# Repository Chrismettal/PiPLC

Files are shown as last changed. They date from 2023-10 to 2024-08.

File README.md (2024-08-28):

# PiPLC <!-- omit in toc -->





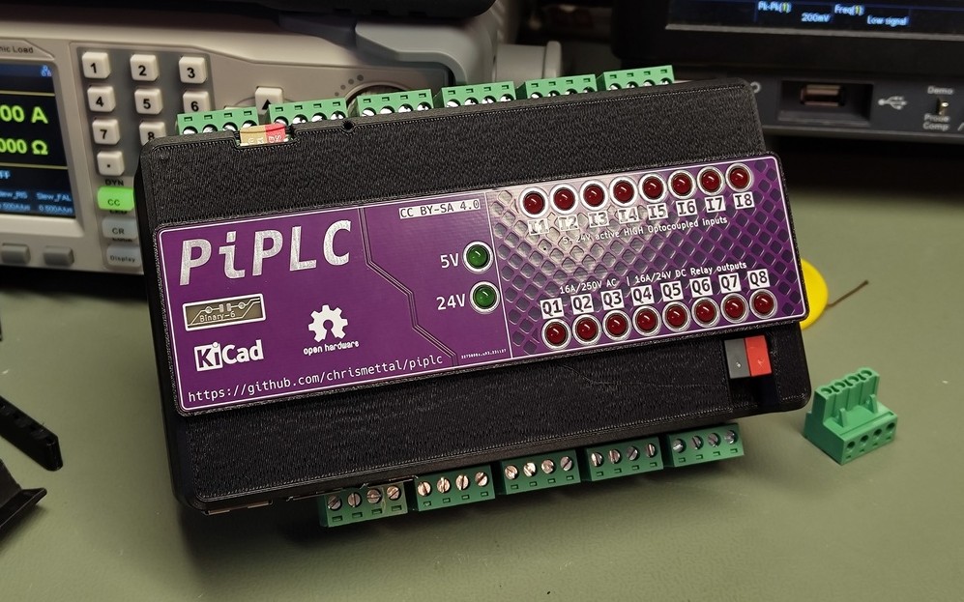
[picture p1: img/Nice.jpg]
Nice


This is a Raspberry Pi breakout board + DIN rail case to use Pis in PLC-like industrial situations.

The design relies on a Raspberry Pi 4 for all functions to work. Pi 5 does also work but won't fit the 3D printed case, while Pi 3 and below don't allow for all functions to be used.

The PiPLC is intended to be used with [Home Assistant](https://www.home-assistant.io/), as well as [OpenPLC](https://autonomylogic.com/).
Obviously, since it's just a breakout board for any Pi, you can run whatever software you want, but Home Assistant and OpenPLC are the ones inspiring the design of this project.

For an example use with your own software, check out [Grass](https://github.com/chrismettal/grass)!

**IO featured on board the PLC are:**

- 8 x 24 V tolerant optocoupled inputs
- 8 x 16A Relays (250 V AC / 24 V DC)
- KNX TP
- Modbus RTU / RS-485
- I²C
- 2 x analog 3.3 V PWM outputs

All the parts are or will be stocked at Tindie!



**If you like my work please consider [supporting me](https://github.com/Chrismettal#donations)!**

## Table of contents <!-- omit in toc -->

- [GPIO mapping](#gpio-mapping)
- [Pinout](#pinout)
- [I/O](#io)
  - [J1 | Power Input](#j1--power-input)
  - [J2 | Modbus](#j2--modbus)
  - [J3 - J6 | Digital Outputs (Q1-8)](#j3---j6--digital-outputs-q1-8)
  - [J7 | PWM](#j7--pwm)
  - [J8 | I²C](#j8--ic)
  - [J9 | 1-Wire](#j9--1-wire)
  - [J10 - J12 | Digital Inputs (I1-8)](#j10---j12--digital-inputs-i1-8)
  - [Wago header | KNX / NCN5121](#wago-header--knx--ncn5121)
- [On board devices](#on-board-devices)
  - [PCF8523 RTC](#pcf8523-rtc)
- [Example Hardware](#example-hardware)
- [Software](#software)
  - [OpenPLC](#openplc)
    - [Installation](#installation)
    - [Example](#example)
  - [Home Assistant](#home-assistant)
    - [Installation](#installation-1)
    - [Example](#example-1)
  - [Codesys](#codesys)
    - [Installation](#installation-2)
    - [Example](#example-2)
- [Raspberry pi configuration](#raspberry-pi-configuration)
  - [`/boot/config.txt`](#bootconfigtxt)
  - [`/boot/cmdline.txt`](#bootcmdlinetxt)
- [Making your own](#making-your-own)
  - [Boards](#boards)
    - [Mainboard](#mainboard)
    - [HMI](#hmi)
    - [Frontpanel](#frontpanel)
    - [Pi Riser](#pi-riser)
    - [HMI Riser](#hmi-riser)
  - [3D printing](#3d-printing)
  - [Impressions](#impressions)
  - [Testing](#testing)
- [Tools used](#tools-used)
- [Sources](#sources)
- [Donations](#donations)
- [License](#license)

---

## GPIO mapping

| GPIO Name | PiPLC function | OpenPLC | Home Assistant | Codesys |
| :---: | :--- | :--- | :--- | :--- |
| `GPIO_02` | :blue_square: I²C SDA | :warning: No driver yet | :warning: To be tested | :warning: To be tested |
| `GPIO_03` | :blue_square: I²C SCL | :warning: No driver yet | :warning: To be tested | :warning: To be tested |
| `GPIO_04` | :blue_square: Modbus TX  | `/dev/ttyAMA3` | `/dev/ttyAMA3` | :warning: To be tested |
| `GPIO_05` | :blue_square: Modbus RX  | `/dev/ttyAMA3` | `/dev/ttyAMA3` | :warning: To be tested |
| `GPIO_06` | :blue_square: Modbus RTS | `/dev/ttyAMA3` | `/dev/ttyAMA3` | :warning: To be tested |
| `GPIO_07` | :red_square: Q4 | `%QX0.3` | :white_check_mark: | :warning: To be tested |
| `GPIO_08` | :red_square: Q3 | `%QX0.2` | :white_check_mark: | :warning: To be tested |
| `GPIO_09` | :yellow_square: I5 | `%IX0.4` | :white_check_mark: | :warning: To be tested |
| `GPIO_10` | :yellow_square: I4 | `%IX0.3` | :white_check_mark: | :warning: To be tested |
| `GPIO_11` | :yellow_square: I6 | `%IX1.5` | :white_check_mark: | :warning: To be tested |
| `GPIO_12` | :red_square: Q5 | `%QX0.4` | :white_check_mark: | :warning: To be tested |
| `GPIO_13` | :yellow_square: I7 | `%IX0.6` | :white_check_mark: | :warning: To be tested |
| `GPIO_14` | :blue_square: KNX TX | :x: | `/dev/ttyAMA0` | :warning: To be tested |
| `GPIO_15` | :blue_square: KNX RX | :x: | `/dev/ttyAMA0` | :warning: To be tested |
| `GPIO_16` | :red_square: Q6 | `%QX0.5` | :white_check_mark: | :warning: To be tested |
| `GPIO_17` | :yellow_square: I1 | `%IX0.0` | :white_check_mark: | :warning: To be tested |
| `GPIO_18` | :orange_square: PWM_0 | `%QW0` | :white_check_mark: | :warning: To be tested |
| `GPIO_19` | :orange_square: PWM_1 | `%QW1` | :white_check_mark: | :warning: To be tested |
| `GPIO_20` | :red_square: Q7 | `%QX0.6` | :white_check_mark: | :warning: To be tested |
| `GPIO_21` | :red_square: Q8 | `%QX0.7` | :white_check_mark: | :warning: To be tested |
| `GPIO_22` | :yellow_square: I3 | `%IX0.2` | :white_check_mark: | :warning: To be tested |
| `GPIO_23` | :blue_square: 1-Wire | :warning: No driver yet | :white_check_mark: | :warning: To be tested |
| `GPIO_24` | :red_square: Q1 | `%QX0.0` | :white_check_mark: | :warning: To be tested |
| `GPIO_25` | :red_square: Q2 | `%QX0.1` | :white_check_mark: | :warning: To be tested |
| `GPIO_26` | :yellow_square: I8 | `%IX0.7` | :white_check_mark: | :warning: To be tested |
| `GPIO_27` | :yellow_square: I2 | `%IX0.1` | :white_check_mark: | :warning: To be tested |

Pins marked unusable with OpenPLC are either not broken out, or differ too much from OpenPLC's mapping. As OpenPLC's mapping is immutable, these pins might not be used if PiPLC is used with the OpenPLC runtime and Pi default hardware layer.

## Pinout

Pinout

---

## I/O

### J1 | Power Input

| 1 | 2 | 3 | 4 |
| :-----: | :-----: | :---: | :---: |
| `+24 V` | `+24 V` | `GND` | `GND` |
 
The PiPLC is to be supplied with 24 V and requires at least a 1 A power supply under full load.

While it will theoretically work at 12 V, the relays used for `Q1-8` require 24V coil voltage to trigger. If you are not placing the relays, feel free to supply your PLC with 12 V though.

Internally, 5V is generated by a `TPS54331D` based DC-DC converter. 
At `J10` 12/24V is passed through unprotected from the power input. 
At `J2` and `J8` 5 V from the DC-DC can be used to draw up to 500mA (protected through a polyfuse). 
At `J3`, 3V3 from the RPI can be used to draw up to 500mA (protected through a polyfuse)

---

### J2 | Modbus

| 1 | 2 | 3 | 4 |
| :----: | :---: | :---: | :---: |
| `+5 V` | :blue_square: `Modbus B` | :blue_square: `Modbus A` | `GND` |

Modbus is an industrial communication protocol often used with PLCs communicating with I/O extensions or other PLCs. 
The wire based one used here is called `Modbus RTU` and is based on half-duplex RS-485 so the header can also be used for that if you dislike Modbus. 

OpenPLC natively supports Modbus to talk to I/O, while Home Assistant has a [Modbus integration](https://www.home-assistant.io/integrations/modbus/).

> [!NOTE]  
> To enable Modbus on your Pi, make sure to enable `UART3` at GPIO5/06.
> This UART is not enabled by default and is only present on Raspberry Pi models 4 and up!
>
> We do NOT enable the `ctsrts` option as we don't want to run with hardware handshakes. We do however need to set/unset the `DE/NRE` pins of the RS485 transceiver IC. How to do this differs based on the chose OS.
>
> In `/boot/config.txt` add:
> 
> `dtoverlay=uart3`
>
> and reboot afterwards
>
> After rebooting you should see the new serial port `/dev/ttyAMA3` when executing `ls /dev/tty*`
>
> For OpenPLC, if you followed the [installation guide](#installation) you should have installed my fork that includes `DE/NRE` control via `GPIO_6` so there should be nothing else for you to do
>

<details>
<summary>Further reading</summary>

https://raspberrypi.stackexchange.com/questions/104464/where-are-the-uarts-on-the-raspberry-pi-4 

https://raspberrypi.stackexchange.com/questions/45570/how-do-i-make-serial-work-on-the-raspberry-pi3-pizerow-pi4-or-later-models/107780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

</details>

---

### J3 - J6 | Digital Outputs (Q1-8)

**J3**

| 1 | 2 | 3 | 4 |
| :---: | :---: | :---: | :---: |
| :red_square: `Q1` | :red_square: `Q1` | :red_square: `Q2` | :red_square: `Q2` |

**J4**

| 1 | 2 | 3 | 4 |
| :---: | :---: | :---: | :---: |
| :red_square: `Q3` | :red_square: `Q3` | :red_square: `Q4` | :red_square: `Q4` |

**J5**

| 1 | 2 | 3 | 4 |
| :---: | :---: | :---: | :---: |
| :red_square: `Q5` | :red_square: `Q5` | :red_square: `Q6` | :red_square: `Q6` |

**J6**

| 1 | 2 | 3 | 4 |
| :---: | :---: | :---: | :---: |
| :red_square: `Q7` | :red_square: `Q7` | :red_square: `Q8` | :red_square: `Q8` |

8 digital outputs are found at the pottom of the device. These outputs are driven by `G5RL-1A-E-TV8` relays theoretically capable of **16 A at 250 V AC** / **16 A at 24 V DC**. 

As with the digital inputs, each output features a status LED found on the HMI subboard.

> [!WARNING]
> As this the PiPLC is an open source passion project and not externally rated by TÜV or a similar agency, usage of these relays in mains powered systems is at your own risk.
> 
> All components chosen are rated for 16 A at 250 V AC and should be capable of driving everything in a home environment.
> 
> Only certified electricians should ever be performing mains work, and home-built devices should never be connected to mains power unless you know what you are doing.

---

### J7 | PWM

| 1 | 2 | 3 | 4 |
| :---: | :---: | :---: | :---: |
| :orange_square: `PWM 0` | :orange_square: `PWM 1` | `GND` | `GND` |

The PWM outputs are intentionally bare, unprotected GPIO connections of `GPIO_18` for `PWM 0` and `GPIO_19` for `PWM 1` so take care not to damage the Pi here. 
If choosing to use the GPIO as inputs, bear in mind that the Pi's GPIO are only 3.3 V tolerant.

Choosing to actually use the PWM outputs, you have both hardware PWM's available to you here.

> [!WARNING]
> Unprotected access to `GPIO_18` and `GPIO_19`. Take care not to damage your Pi!

---

### J8 | I²C

| 1 | 2 | 3 | 4 |
| :----: | :---: | :---: | :---: |
| `+5 V` | `GND` | :blue_square: `I²C SDA` | :blue_square: `I²C SCL` |

Here you have a protected, somewhat isolated 5 V tolerant I²C header with integrated pullups. This was at first intended for connecting to extensions, but the Modbus header takes care of that now.
You do have the option however, to attach whatever I²C device you want, provided the runtime you are using supports I²C communication.

> [!WARNING]
> The I²C contacts are already pulled up to 5 V so do not connect any 3.3 V only I²C devices directly without isolation!

> [!NOTE]
> To enable I²C, go into `/boot/config.txt` and uncomment `dtparam=i2c_arm=on`, or alternatively enable I²C through `sudo raspi-config`
>
> You might need to install `i2c-tools` with `sudo apt install i2c-tools` to test your I²C connections. 
>
> `i2cdetect -y 1` should show the adresses of all found I²C devices afterwards

---

### J9 | 1-Wire

| 1 | 2 | 3 | 4 |
| :---: | :---: | :---: | :---: |
| `+ 3.3 V` | `GND` | :blue_square: `1-Wire` | :blue_square: `1-Wire` |

This header contains `GPIO_04` for native 1-Wire capability. 

1-Wire is usually used for temperature sensors, like `DS18B20`, or battery voltage sensing, but is sometimes also used for access control with iButtons.

> [!WARNING]
> Unprotected access to `GPIO_04`. Take care not to damage your Pi!

> [!NOTE]
> To enable 1-Wire, add the following to `/boot/config.txt`:
> 
> `dtoverlay=w1-gpio,gpiopin=23`
>
> reboot
>
> You should be able to find any connected 1-Wire devices automatically with `ls /sys/bus/w1/devices/` afterwards

---

### J10 - J12 | Digital Inputs (I1-8)

**J10**

| 1 | 2 | 3 | 4 |
| :-----: | :-----: | :-----: | :-----: |
| `+24 V` | `+24 V` | `+24 V` | `+24 V` |

**J11**

| 1 | 2 | 3 | 4 |
| :---: | :---: | :---: | :---: |
| :yellow_square: `I4` | :yellow_square: `I3` | :yellow_square: `I2` | :yellow_square: `I1` |

**J12**

| 1 | 2 | 3 | 4 |
| :---: | :---: | :---: | :---: |
| :yellow_square: `I8` | :yellow_square: `I7` | :yellow_square: `I6` | :yellow_square: `I5` |

8 digital inputs are found at the top of the device. These inputs are 5-24 V tolerant current sinking inputs through `EL817C` optocouplers. 
J10 features 24 V outputs to easily supply switches or other sensors feeding back into J11-J12 as inputs.

All inputs feature a status//Order is intentional to match the GPIO mapping table of PiPLC at https://github.com/chrismettal/piplc#gpio-mapping
//while having all relays mapped "in order" from left to right LED driven by the optocoupler output, thus not loading the input. 

On the Raspberry side, pullups need to be enabled on the GPIOs to enable reading from these input stages.

The inputs require 5mA of input current to reliably trigger at 24 V.

---

### Wago header | KNX / NCN5121

Utilizing [knxd](https://github.com/knxd/knxd/tree/main) to run a [NCN5121](https://www.onsemi.com/pdf/datasheet/ncn5121-d.pdf) KNX transceiver chip the PiPLC can talk to KNX networks natively, without going through an actual KNX-IP gateway first. (Internally, knxd looks like a KNX-IP gateway, but it won't route through your actual LAN)

For Home Assistant, there is [an addon for knxd](https://github.com/da-anda/hass-io-addons/tree/main/knxd), so Home Assistant sees the internal NCN5121 as a KNX-IP gateway @ localhost.

See the [knxd documentation](https://github.com/knxd/knxd/blob/main/doc/inifile.rst#ncn5120) for specifics on how to use the driver if you are not using Home Assistant.

In this board, the `NC5121` is NOT supplied through the KNX supply, but through the Pi's `3v3` rail. This means that it doesn't need to be taken into account when calculating the KNX power supply needs.

> [!NOTE]  
> To enable KNX, make sure to disable bluetooth and the serial console on your Pi
> This is required to enable full `UART0` at GPIO14/15
>
> In `/boot/config.txt` add:
> 
> `dtoverlay=pi3-disable-bt`
>
> In `/boot/cmdline.txt` remove:
> 
> `console=serial0,115200` or `console=ttyAMA0,115200` if found
>
> reboot
>
> In your OS, `/dev/ttyAMA0` can now be used as your KNX interface
>

---

## On board devices

### PCF8523 RTC

A `PCF8523` based realtime clock is present on the board so the PiPLC can keep track of time even when its 24 V input drops.

> [!NOTE]  
>
> To enable the real time clock on your Pi, add the following to `/boot/config.txt`:
>
> `dtoverlay=i2c-rtc,pcf8523`
>
> And reboot afterwards.
>
> Enabling RTC in the Pi and setting the time correctly is explained well in [Adafruit's RTC guide](https://learn.adafruit.com/adding-a-real-time-clock-to-raspberry-pi/set-rtc-time).

---

## Example Hardware

TestBoardSchematic

This is the testing "schematic" used for all software examples. It demonstrates all interfaces present on-board and all testing of PiPLC was done in this configuration.

| GPIO Name | PiPLC function | Device |
| :---: | :--- | :--- |
| `GPIO_02 - 03` | :blue_square: I²C | `PCA9685` 16 Ch. PWM servo driver |
| `GPIO_04 - 06` | :blue_square: Modbus  | EBYTE `MA01-XACX0440` I/O Module |
| `GPIO_04 - 06` | :blue_square: Modbus  | ARCELI `SHT20` Temp + Humidity probe |
| `GPIO_24` | :red_square: Q1 | 230 V Light |
| `GPIO_08` | :red_square: Q3 | Stacklight Green Channel |
| `GPIO_07` | :red_square: Q4 | Stacklight Yellow Channel |
| `GPIO_12` | :red_square: Q5 | Stacklight Red Channel |
| `GPIO_17` | :yellow_square: I1 | `S0` Home power meter |
| `GPIO_27` | :yellow_square: I2 | Light switch |
| `GPIO_22` | :yellow_square: I3 | Emergency Stop NO |
| `GPIO_10` | :yellow_square: I4 | Emergency Stop NC |
| `GPIO_09` | :yellow_square: I5 | Toggle Switch left |
| `GPIO_11` | :yellow_square: I6 | Toggle Switch right |
| `GPIO_13` | :yellow_square: I7 | Green button |
| `GPIO_26` | :yellow_square: I8 | Red button |
| `GPIO_14 - 15` | :blue_square: KNX | 4 Ch. Relay |
| `GPIO_18` | :orange_square: PWM_0 | Dimmable LED |
| `GPIO_19` | :orange_square: PWM_1 | Dimmable LED |
| `GPIO_23` | :blue_square: 1-Wire  | `DS18B20` Temperature probe |
| USB | USB | Arduino Uno (OpenPLC Slave Firmware) |
| RJ45 Jack | EtherCAT | TBD |
| Wifi | LAN access | Android Tablet as HMI |
| Wifi | LAN access | Programming device (Laptop) |

There is an example chinesium Modbus I/O module on the testing board with the following information:

| Parameter | Value |
| :--- | :--- |
| Device Type | Generic Modbus RTU Device |
| Slave ID | 32 |
| COM Port | `/dev/ttyAMA3` |
| Baudrate | 9600 |
| Parity | None |
| Data bits | 8 |
| Stop bits | 1 |
| Transmission Pause | 0 |
| Discrete Inputs | Address 0, Size 0 |
| Coils | Address 0, Size 4 |
| Input Registers | Address 0, Size 0 |
| Holding Registers - Read  | Address 0, Size 0 |
| Holding Registers - Write | Address 0, Size 0 |

---

## Software

### OpenPLC

[OpenPLC](https://autonomylogic.com/) is a Fully `IEC 61131-3` compliant, open source, multi-hardware programmable logic controller suite.

Consisting of a separate runtime and editor, it can run on regular PCs as a soft PLC, as well as a multitude of embedded systems. (Think Beckhoff XAR / XAE)

I am currently creating a hardware layer for PiPLC at https://github.com/Chrismettal/OpenPLC_v3. This should allow easy adressing of all IO while enabling native use of Modbus and other interfaces. The regular "Rpi" layer should also be compatible, but I²C, Modbus and KNX might not work, and I1-8 / Q1-8 adressing might be a bit unintuitive (See [GPIO mapping table](##-GPIO-mapping))

#### Installation

<details>
<summary>Click to expand</summary>

1. You are going to need a fresh installation of [Raspberry Pi OS](https://www.raspberrypi.com/software/) on your Pi 4. There is an official [getting started guide](https://www.raspberrypi.com/documentation/computers/getting-started.html) that is being kept up to date, so the first steps are not further described here.

2. Execute `git clone https://github.com/chrismettal/OpenPLC_v3` on your Pi. This will clone a forked version of the OpenPLC runtime that contains some changes to make it compatible with PiPLC. Should these changes get merged, this link will be changed to point to the official version.

3. `cd OpenPLC_v3` to enter the just cloned folder

4. `./install rpi` will start the full OpenPLC installation. (This will take a few minutes)

5. After a reboot, your OpenPLC installation's webinterface should be accessible on port 8080 on your Pi. Either try to access it at `127.0.0.1:8080` locally on your pi, or access it through your Pi's IP adress in your host computer.

6. The default credentials will be `Name: openplc`, `Password: openplc`. You might want to change these right after logging in for the first time. To do so, use the "Users" tab and edit the default "openplc" account:

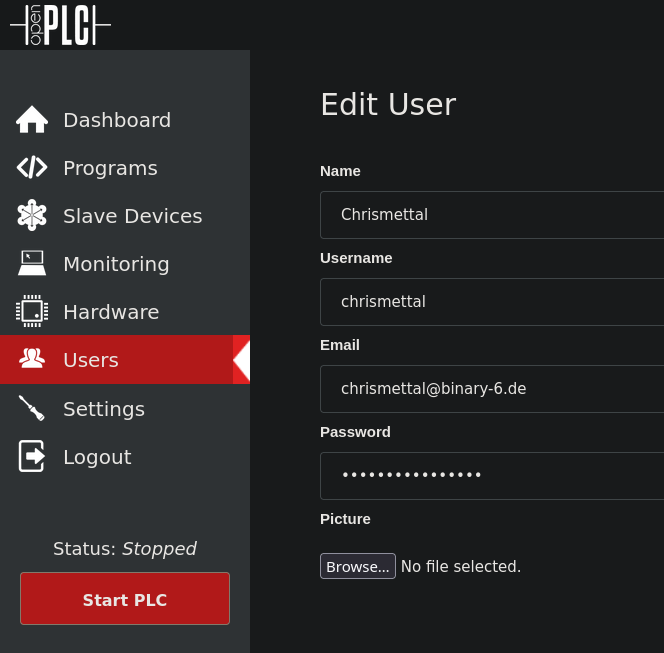
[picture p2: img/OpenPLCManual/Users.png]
OpenPLCUsers


7. Head over to the "Hardware" tab to select the hardware layer. Select and save the "PiPLC" layer (Exact name might differ once merged upstream):

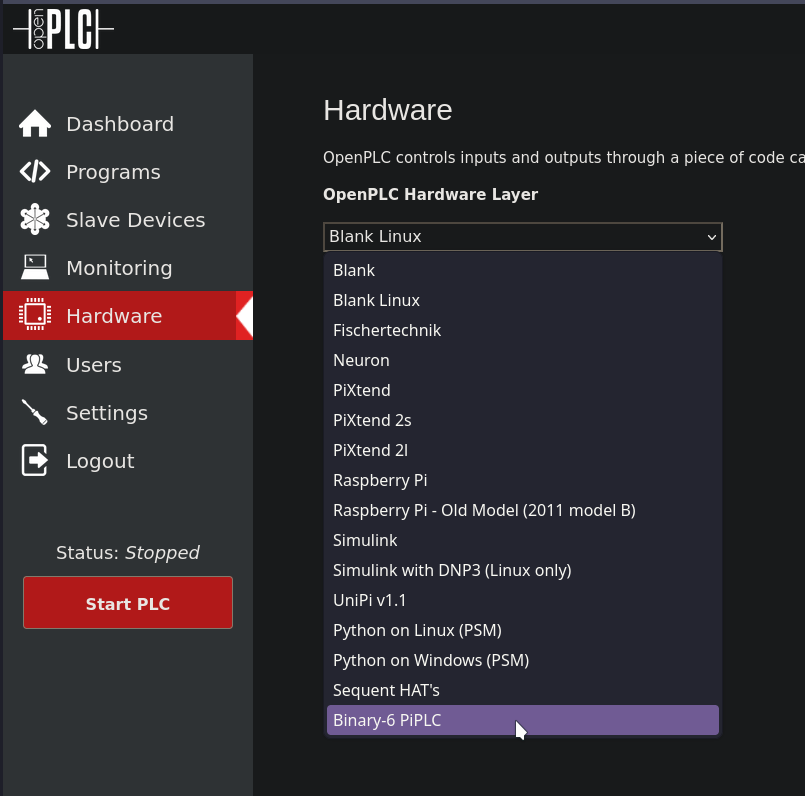
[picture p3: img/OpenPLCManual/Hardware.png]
OpenPLCHardware


8. That should be it for a base installation. You should now have access to D1-8 and Q1-8 already, but you won't see Modbus RTU yet for slave devices. Instructions how to enable the Modbus COM port are found at [J2 | Modbus](#j2--modbus).

9. After enabling UART3 [as described above](#j2--modbus) and rebooting your Pi, you should see `/dev/ttyAMA3` be available as a COM port for Modbus slaves:

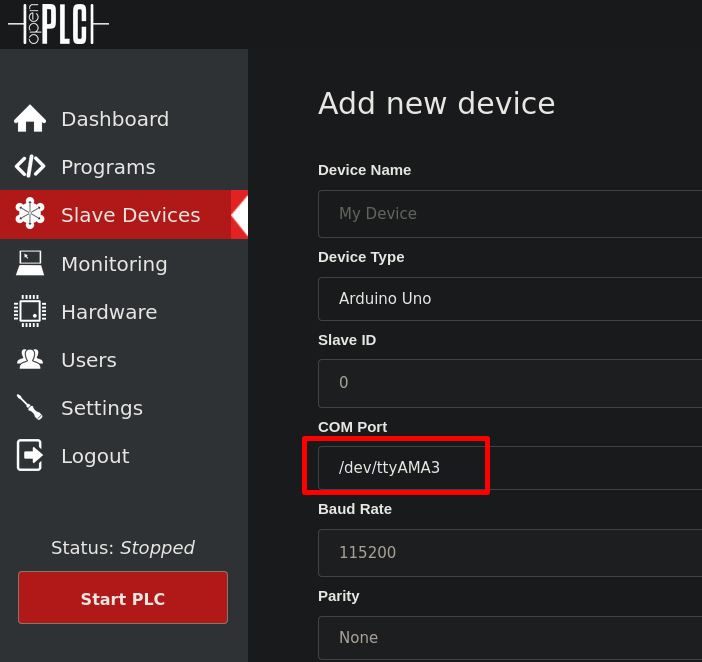
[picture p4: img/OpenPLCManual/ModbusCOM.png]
ModbusCOM


10. That's all there is to install the base OpenPLC install. There is currently no easy way to enable KNX or 1-Wire connectivity, and while I²C connectivity from OpenPLC is possible, it is currently not implemented in the hardware layer. All of these might be done in future within said hardware layer. See the usage example below for further information. Also see the [OpenPLC getting started guide](https://autonomylogic.com/docs/openplc-overview/) for general instructions on how to upload code to your OpenPLC instance

</details>

#### Example

Check out `/src/OpenPLC`!

---

### Home Assistant

[Home Assistant](https://www.home-assistant.io/) is an open source smart-home automation software, that provides logic, visualization and automation in a single place. It allows you to connect practically everything to your home under one interface, awakening your smart home.

Home Assistant seems to move away from local hardware IO a bit, instead focussing on devices in your LAN / WiFi. That doesn't mean though, that it isn't fully capable of running on an actual PLC, giving you control of your devices without a middle man or WiFi shenanigans. This is where the `NC5121` KNX interface comes into play, which enables you to talk to a vast variety of off-the-shelf decentralised ACTUAL smart home components (No supplier apps, no accounts, no telemetry) without needing to go through an KNX-IP interface first.

#### Installation

<details>
<summary>Click to expand</summary>

1. Follow the [official first steps](https://www.home-assistant.io/installation/raspberrypi) for a standard Home Assistant Raspberry Pi installation

2. Also follow the [official onboarding steps](https://www.home-assistant.io/getting-started/onboarding/) to create your Home Assistant account and generally be able to use the system

3. Power down your Home Assistant install and take out the SD card

4. Install the SD card in a linux computer

5. Mount the first partition (Should be a 32MB one) temporarily to your system:

```
mkdir ~/TempMount

sudo mount -t vfat /dev/sdx1 ~/TempMount
```

6. In the now mounted `TempMount` directory, you will find `Config.txt` where we can set dtoverlays to enable additional serial ports etc.

7. Follow both the [KNX enabling guide](#wago-header--knx--ncn5121) as well as the [Modbus enabling guide](#j2--modbus), adding their specific dtoverlays to `Config.txt`. This will make sure the Pi knows to enable the required UART connections there.

8. You can now unmount the drive with `sudo umount ~/TempMount` and put the SD card back in your Pi before booting Home Assistant back up

9. To enable KNX communication, you'll need to install the [knxd addon](https://github.com/da-anda/hass-io-addons). 

10. Configure the `knxd` daemon as shown in the following picture. The `/dev/ttyAMA0` interface makes sure we are talking to our on-board `NC5121`. Theoretically you could also use a KNX-USB interface if you weren't using the PiPLC board. Don't forget to start the daemon and set it to autostart.

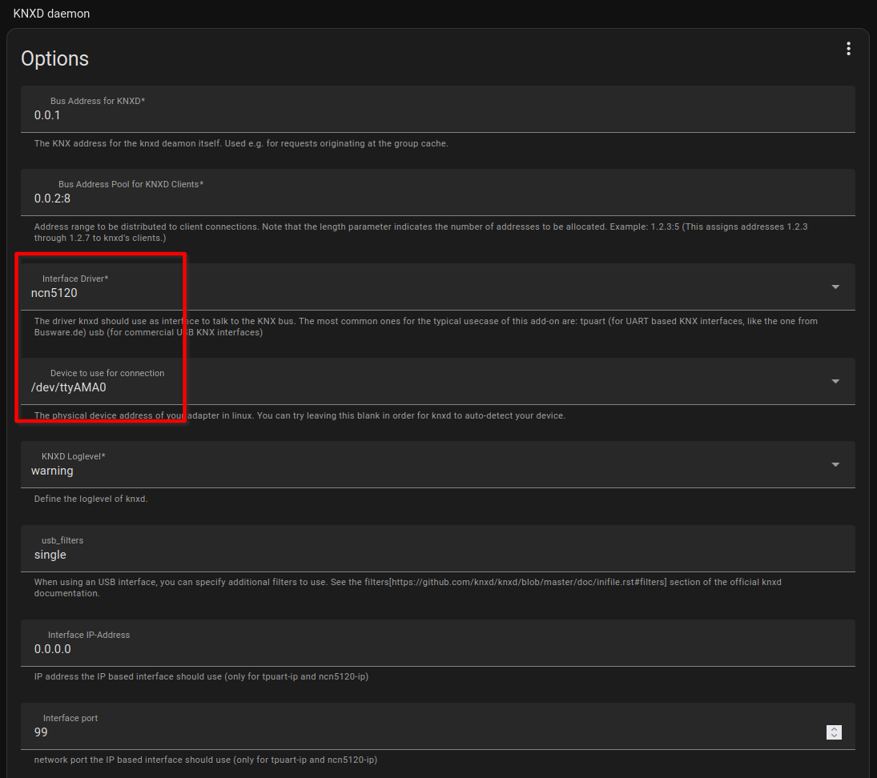
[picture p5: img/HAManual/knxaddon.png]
knxaddon


11. Once the `knxd` deamon is running install the `KNX` integration:

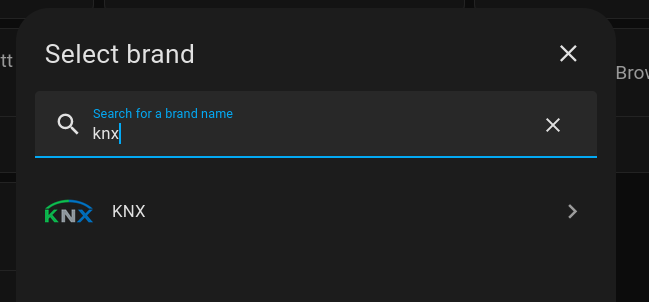
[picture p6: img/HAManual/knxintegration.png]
KNX integration


12. During initial setup of the `KNX` integration, it should find your local `knxd` daemon instance as a valid interface.

13. To control / read your local GPIO, you'll want to install the following custom integration:

[ha-rpi_gpio](https://github.com/thecode/ha-rpi_gpio)

14. To read 1-wire sensors through GPIO, you'll want to install the following custom integration:

[ha-onewire-sysbus](https://github.com/thecode/ha-onewire-sysbus)

</details>

#### Example

TODO Upload example `configuration.yaml`

---

### Codesys

Codesys, like OpenPLC is a `IEC 61131-3` compliant PLC runtime, compatible with PiPLC. It is not open source and the [license for the RPI runtime](https://store.codesys.com/codesys-control-for-raspberry-pi-sl.html) costs about 55€. PiPLC was designed for OpenPLC but Codesys (as of 2024-01) is a much more robust runtime with more features.

As Codesys is proprietary, I won't be focussing much on it, but I want to make sure that most functions work well with PiPLC.

#### Installation

<details>
<summary>Click to expand</summary>

1. Setup your Pi with a fresh install of Pi OS. I only had luck using the "legacy" 32 Bit Debian Buster install and not the most recent (as of 2024-02) Debian Bookworm. (Wiringpi?)

2. Follow the [Codesys Pi FAQ](https://faq.codesys.com/display/CDSFAQ/Raspberry+Pi%3A+FAQ) to install the runtime on your Pi as well as to get your engineering system set up

3. After enabling UART3 [as described above](#j2--modbus) and rebooting your Pi, you can set `/dev/ttyAMA3` to be your Modbus master port:

TODO Modbus port image
TODO I²C port settings
TODO 1-Wire port settings

</details>

#### Example

Check out `/src/CODESYS`!

---

## Raspberry pi configuration

### `/boot/config.txt`

```
# PiPLC
dtoverlay=uart3                     # Enable UART3 for Modbus
dtoverlay=pi3-disable-bt            # Disable Bluetooth so that UART0 is free for KNX
dtoverlay=w1-gpio,gpiopin=23        # Enable the 1-Wire pus on pin 23
dtoverlay=i2c-rtc,pcf8523           # Enable the I²C RTC
gpio=24,25,8,7,12,16,20,21=op,dl    # Set all relay pins to outputs and turn them off
gpio=17,27,22,10,9,11,13,26=ip,pu   # Set all digital input pins as pulled-up inputs
```

remove any mention of I²S or SPI if found, otherwise relay GPIOs might be driven HIGH on boot. Sometimes `dtparam=spi=on
` is set which will ruin your day so comment that one out if found.

### `/boot/cmdline.txt`

remove `console=serial0,115200` and/or `console=ttyAMA0,115200` if found.

---

## Making your own

### Boards

A full PiPLC consists of several subboards that need to be manufactured individually. 
Theoretically only the mainboard is technically required, as you could use wires to manually connect the Pi to the PLC 
as well as just not using the HMI as it is only a status display at the moment, 
but the existing 3D printable case assumes all boards to be used.

Only the main board has SMD parts that need to be assembled, so only one board will need to go through PCBA.

All boards are designed to be manufactured by JLCPCB, with BOMs using LCSC partnumbers attached.
ALso all boards are to be manufactured with regular 1.6mm thickness, lead free HASL and 1oz copper weight.

---

#### Mainboard

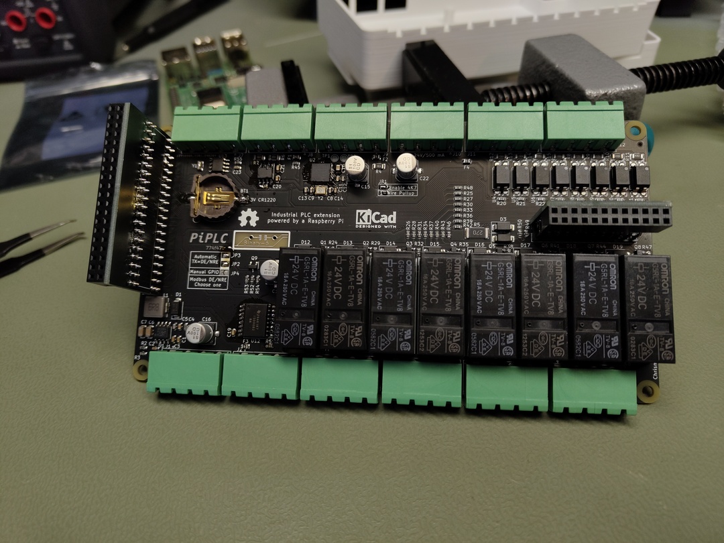
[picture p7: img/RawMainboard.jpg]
Mainboard


[Interactive Bom / Online view](https://htmlpreview.github.io/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)

This board houses all logic and is the only one that benefits from a PCBA service. All other boards plug into here, including the Raspberry Pi.

---

#### HMI

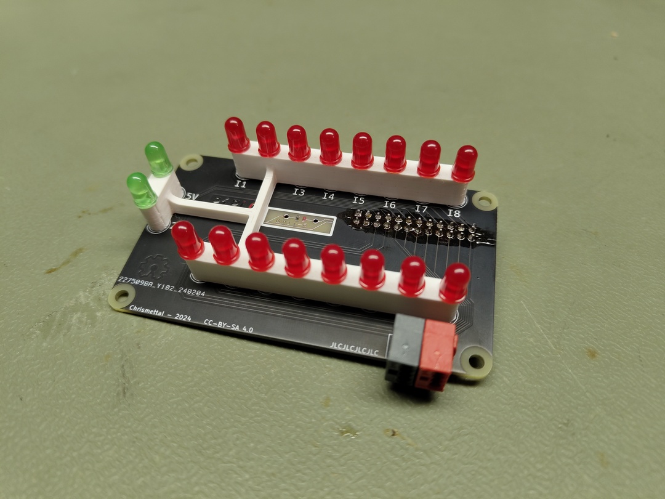
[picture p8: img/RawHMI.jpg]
HMI


[Interactive Bom](https://htmlpreview.github.io/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)

While not strictly required, this board houses frontpanel LEDs for status view of digital inputs and outputs, as well as 5V and 24V power status LEDs.

Additionally, the Wago header to plug into a KNX network is housed on this board.

---

#### Frontpanel

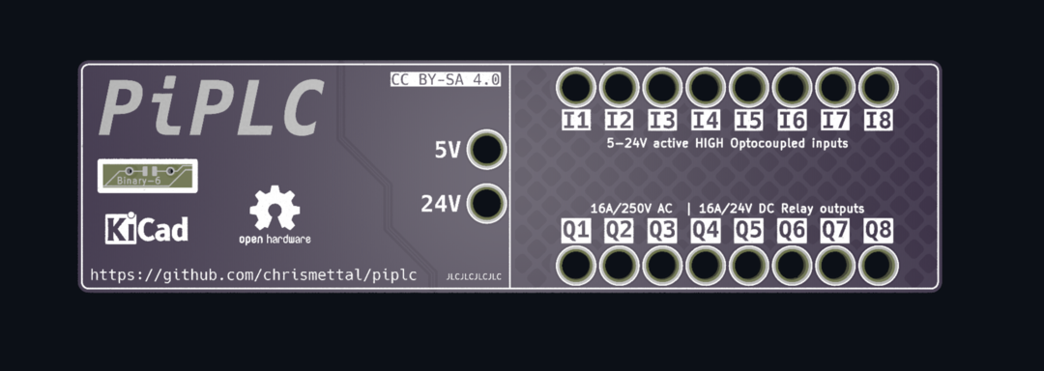
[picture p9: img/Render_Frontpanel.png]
Render_Frontpanel


[Interactive Bom / Online view](https://htmlpreview.github.io/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)

Purely for decoration / labelling. No electrical connections here. Can theoretically be replaced by a sticker.

---

#### Pi Riser

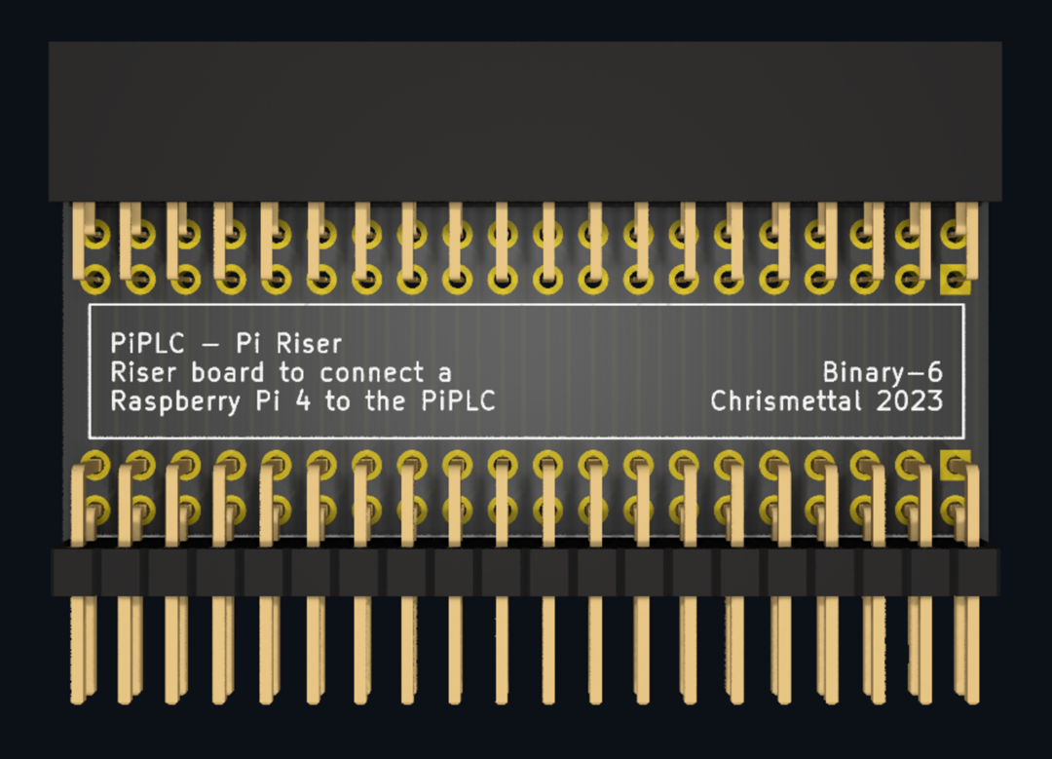
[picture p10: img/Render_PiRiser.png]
Render_PiRiser


[Interactive Bom / Online view](https://htmlpreview.github.io/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)

Riser board to give the Pi enough clearance to connect face-down to the mainboard. Can theoretically be replaced by a ribbon cable.

---

#### HMI Riser

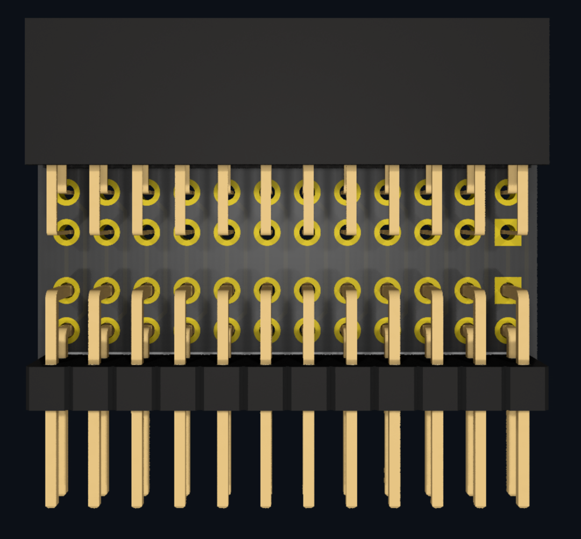
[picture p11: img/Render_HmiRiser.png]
Render_HmiRiser


[Interactive Bom / Online view](https://htmlpreview.github.io/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)

Riser board to connect the HMI board to the mainboard. Can theoretically be replaced by a ribbon cable

---

### 3D printing

A 3D printable case is provided in `/3d_printing`.

The case just snapfits together, after all boards were installed using M3x5mm screws.

Currently it will only fit a Raspberry Pi 4 and will not work with a Pi 5! You could modify the case to make a Pi 5 fit but I haven't done that yet.

The DIN-Rail mount on the back is not optimal yet so the compliant snap-action might now work, but since all boards I have manufactured are now deployed, I haven't yet gone around to updating the case.

The case is intended to be printed in a isolating and/or flame retardant filament like `PC` or `PETG VO`. 

---

### Impressions

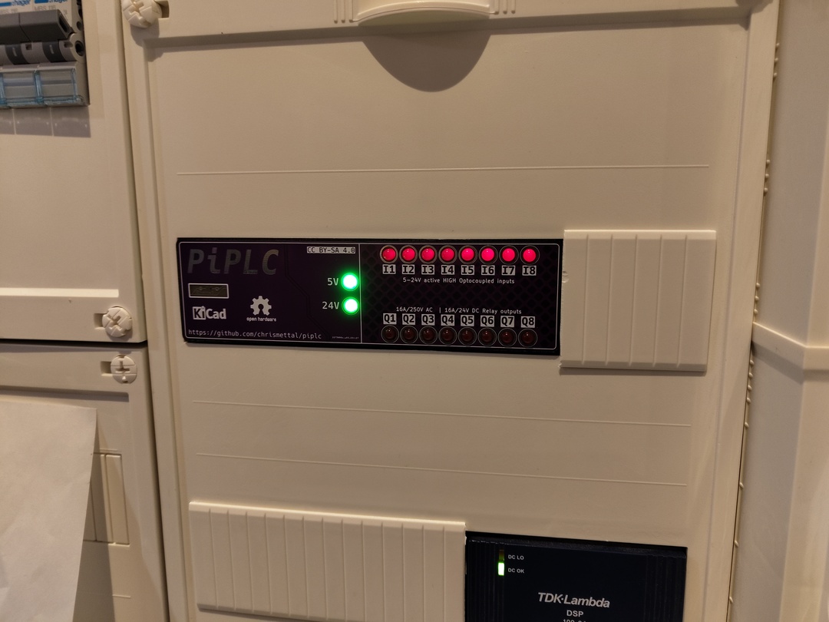
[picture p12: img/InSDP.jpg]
InSDP


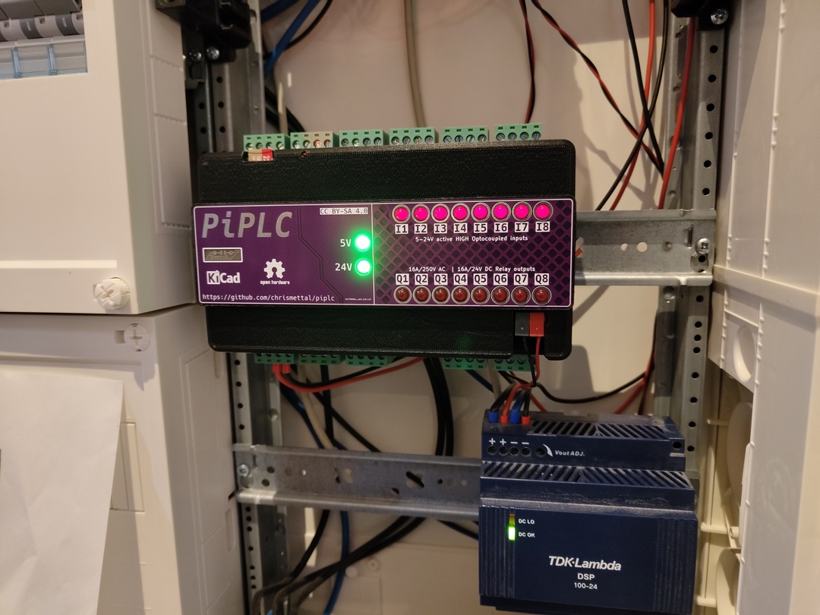
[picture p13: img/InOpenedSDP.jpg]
InOpenedSDP


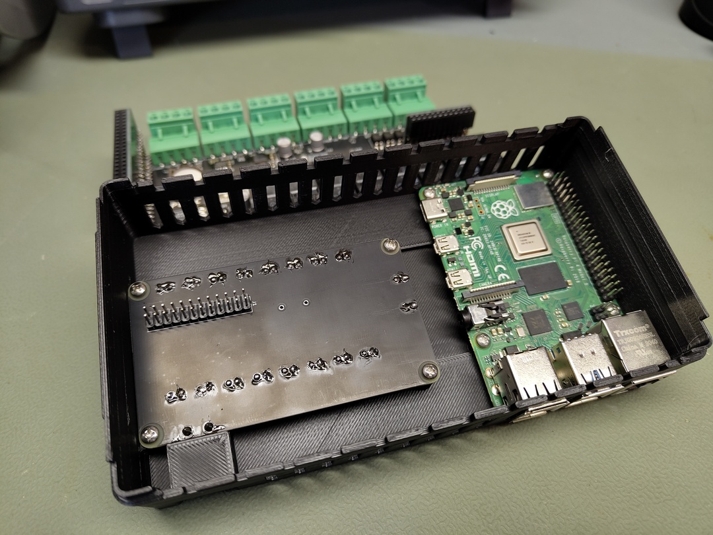
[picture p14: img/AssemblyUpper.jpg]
AssemblyUpper


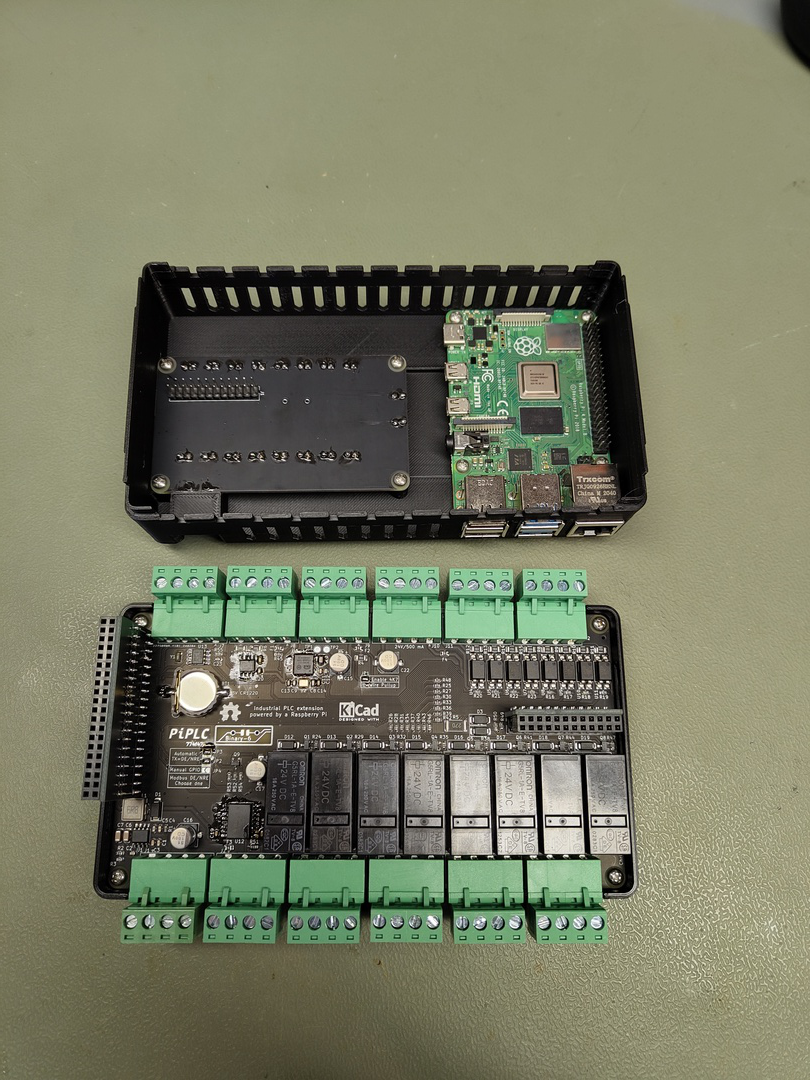
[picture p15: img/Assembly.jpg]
Assembly

 
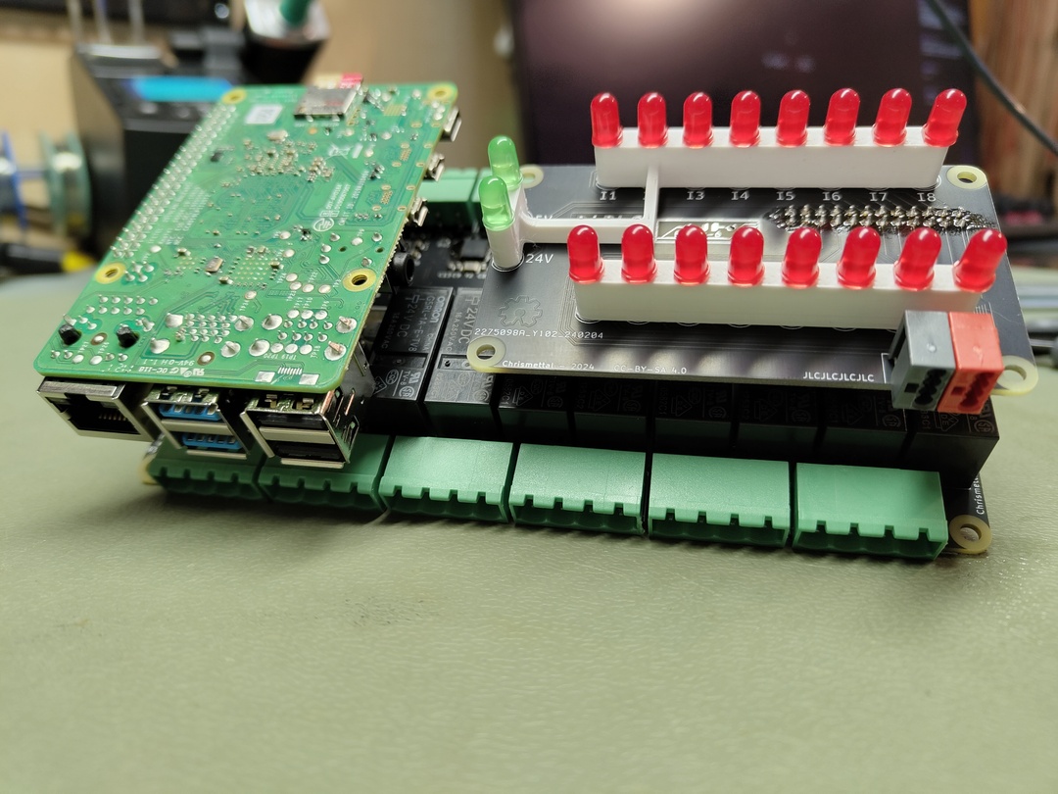
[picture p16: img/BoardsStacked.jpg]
BoardsStacked


---

### Testing

The following commands can be used to test your hardware configuration without installing PLC code or a full Home Assistant install. These are to be executed on a regular Pi OS install with `raspi-gpio` installed.

- Enable pull ups on all input pins

`raspi-gpio set 17,27,22,10,9,11,13,26 pu`

- Set all output relay pins to be outputs

`raspi-gpio set 24,25,8,7,12,16,20,21 op`

- Read state of all input pins

`raspi-gpio get 17,27,22,10,9,11,13,26`

- Set individual relays HIGH/LOW (See [GPIO mapping](#gpio-mapping))

`raspi-gpio set 24 dh` / `raspi-gpio set 24 dl`

- Detect connected I²C devices (Should show found addresses in the grid if properly connected)

`i2cdetect -y 1`

---

## Tools used

- FreeCAD 0.21.2
  - KicadStepUp Workbench 10.20.7
- KiCAD 7.0.9

---

## Sources

- Wago 243-211 KNX Connector 3D file - https://grabcad.com/library/knx-connector-1
- Raspberry Pi 3D file - https://grabcad.com/library/raspberry-pi-4-model-b-1
- PCB Standoffs 3D files - https://grabcad.com/library/ettinger-standoff-nickel-plated-brass-m-f-m2-m8-1/details?folder_id=12725833

---

## Donations

**If you like my work please consider [supporting me](https://github.com/Chrismettal#donations)!**

---

## License

 <br />This work is licensed under a <a rel="license" href="http://creativecommons.org/licenses/by-sa/4.0/">Creative Commons Attribution-ShareAlike 4.0 International License</a>.

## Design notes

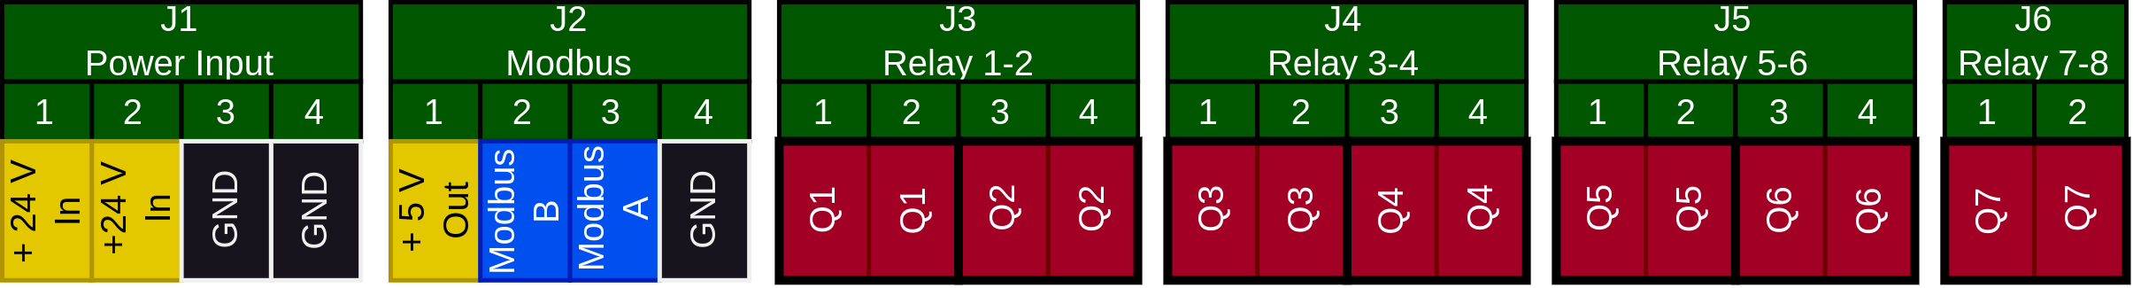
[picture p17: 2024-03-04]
doc/PiPLC_labels_Bot.png

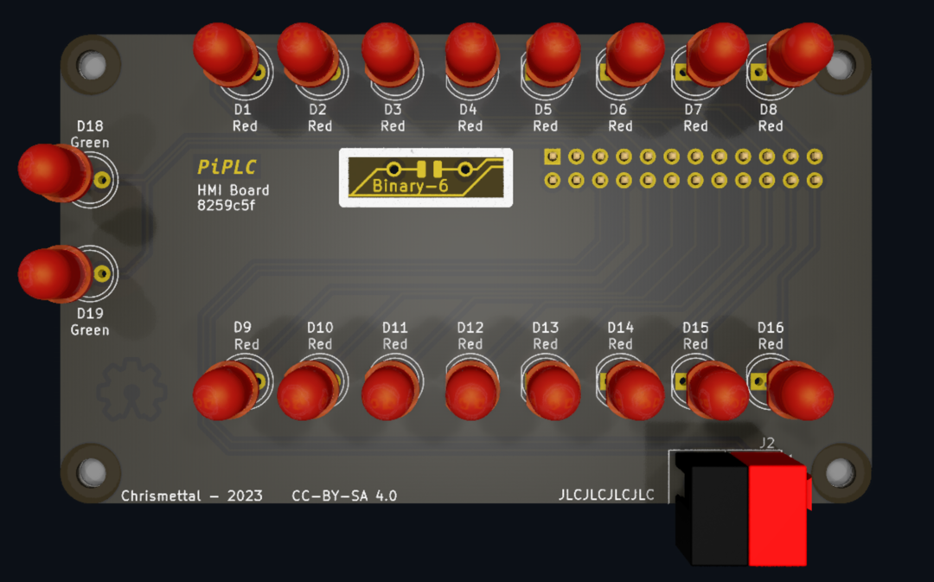
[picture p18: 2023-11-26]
img/Render_HMI.png

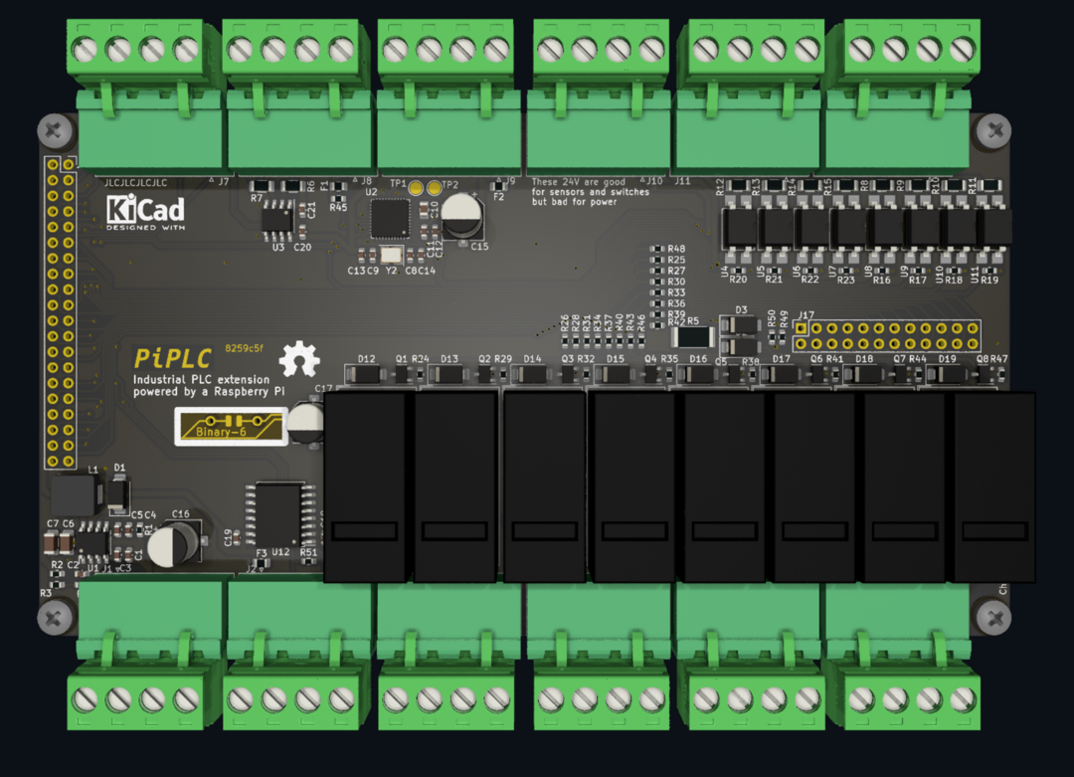
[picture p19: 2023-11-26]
img/Render_Mainboard.png

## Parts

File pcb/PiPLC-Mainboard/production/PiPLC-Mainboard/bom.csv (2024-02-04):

Designator | Footprint | Quantity | Value | LCSC Part #
BT1 | CR1220_Holder | 1 | CR1220 (3V) | C70381
C1, C2, C3 | 0603 | 3 | 10nF | C57112
C10 | 0805 | 1 | 220nF | C5378
C11 | 0603 | 1 | 47nF | C1622
C12, C13, C14, C18, C19, C20, C21 | 0603 | 7 | 100nF | C14663
C15, C16, C17, C22 | CP_Elec_6.3x7.7 | 4 | 100uF | C134220
C23 | 0603 | 1 | 2.2µF | C23630
C4 | 0603 | 1 | 4.7nF | C53987
C5 | 0603 | 1 | 33pF | C1663
C6, C7 | 1206 | 2 | 47uF | C96123
C8, C9 | 0603 | 2 | 10pF | C1634
D1 | D_SMA | 1 | B340 | C85098
D12, D13, D14, D15, D16, D17, D18, D19, D2 | D_SMA | 9 | SS14 | C2480
D3 | D_SMA | 1 | SMAJ40CA | C223989
F1, F2, F3, F4 | 0805 | 4 | 500mA | C2833485
J1, J10, J11, J12, J2, J3, J4, J5, J6, J7, J8, J9 | PhoenixContact_MSTBA_2,5_4-G-5,08_1x04_P5.08mm_Horizontal | 12 | WJ2EDGRC-5.08-4P | C8446
J17 | PinSocket_2x12_P2.54mm_Vertical | 1 | Conn_02x12_Odd_Even
J99 | PinSocket_2x20_P2.54mm_Vertical | 1 | Rpi GPIO
JP1 | SolderJumper-2_P1.3mm_Open_TrianglePad1.0x1.5mm | 1 | 1-Wire Pullup
JP2 | SolderJumper-2_P1.3mm_Open_TrianglePad1.0x1.5mm | 1 | Auto_DE/NRE_2
JP3 | SolderJumper-2_P1.3mm_Open_TrianglePad1.0x1.5mm | 1 | Auto_DE/NRE_1
JP4 | SolderJumper-2_P1.3mm_Open_TrianglePad1.0x1.5mm | 1 | GPIO23_DE/NRE
K1, K2, K3, K4, K5, K6, K7, K8 | Relay_SPST_Omron_G2RL-1A-E_GroundMod | 8 | G5RL-1A-E-TV8 DC24 | C2896748
L1 | Sunltech_SLO0630H | 1 | 6.8uH | C207841
Q1, Q2, Q3, Q4, Q5, Q6, Q7, Q8 | SOT-23-3 | 8 | AO3400A | C20917
Q9 | SOT-23 | 1 | SS8550 Y2 | C8542
R1 | 0603 | 1 | 47K | C25819
R10, R11, R12, R13, R14, R15, R4, R6, R7, R8, R9 | 1206 | 11 | 4K7 | C17936
R16, R17, R18, R19, R20, R21, R22, R23, R25, R27, R30, R33, R36, R39, R42, R48, R55 | 0603 | 17 | 1K2 | C22765
R2, R24, R29, R32, R35, R38, R41, R44, R47, R49, R50, R52, R53 | 0603 | 13 | 10K | C25804
R26, R28, R31, R34, R37, R40, R43, R46 | 0603 | 8 | 100R | C22775
R3 | 0603 | 1 | 1.8k | C4177
R45 | 0603 | 1 | 1.5k | C22843
R5 | 2512 | 1 | 27R | C25478
R51 | 0603 | 1 | 120R | C22787
R54 | 0603 | 1 | 7K5 | C23234
U1 | SOIC-8_3.9x4.9mm_P1.27mm | 1 | TPS54331D | C9865
U10, U11, U4, U5, U6, U7, U8, U9 | Optocoupler_DIP_S1 | 8 | EL817C | C106900
U12 | SOIC-16W_7.5x10.3mm_P1.27mm | 1 | ISO3082DWR | C21710
U13 | SOIC-8_3.9x4.9mm_P1.27mm | 1 | PCF8523T | C2651516
U2 | QFN-40-1EP_6x6mm_P0.5mm_EP4.6x4.6mm | 1 | NCN5121 | C891972
U3 | SOIC-8_3.9x4.9mm_P1.27mm | 1 | ISO1540 | C179739
Y1 | Crystal_SMD_3215-2Pin_3.2x1.5mm | 1 | 32.768kHz | C32346
Y2 | Crystal_SMD_3225-4Pin_3.2x2.5mm | 1 | 16MHz | C13738

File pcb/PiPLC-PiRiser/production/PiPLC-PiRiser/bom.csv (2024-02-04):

Designator | Footprint | Quantity | Value | LCSC Part #
J1 | PinHeader_2x20_P2.54mm_Horizontal | 1 | Male | C2895000
J2 | PinSocket_2x20_P2.54mm_Horizontal | 1 | Female | C2897440

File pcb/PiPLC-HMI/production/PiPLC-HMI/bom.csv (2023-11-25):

Designator | Footprint | Quantity | Value | LCSC Part #
D1, D10, D11, D12, D13, D14, D15, D16, D2, D3, D4, D5, D6, D7, D8, D9 | LED_D5.0mm | 16 | Red | C417347
D18, D19 | LED_D5.0mm | 2 | Green | C2764903
J1 | PinHeader_2x12_P2.54mm_Vertical | 1 | Conn_02x12_Odd_Even | C2894973

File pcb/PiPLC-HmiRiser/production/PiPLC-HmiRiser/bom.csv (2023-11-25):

Designator | Footprint | Quantity | Value | LCSC Part #
J1 | PinHeader_2x12_P2.54mm_Horizontal | 1 | Male
J2 | PinSocket_2x12_P2.54mm_Horizontal | 1 | Female

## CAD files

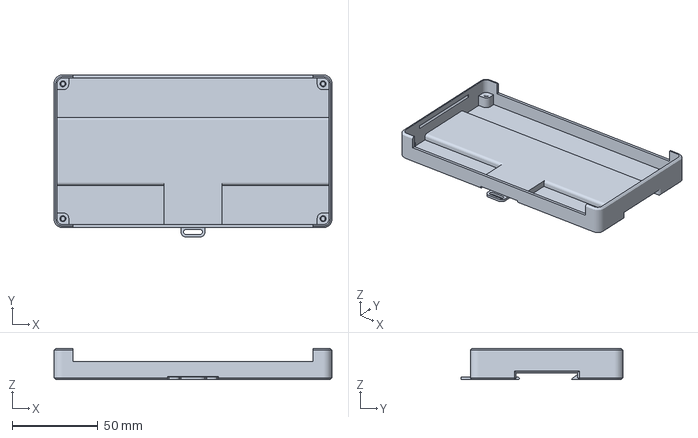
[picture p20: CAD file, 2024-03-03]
3d_printing/3d/PiPLC-CaseBot.3mf
162.0 x 94.5 x 18.2 mm

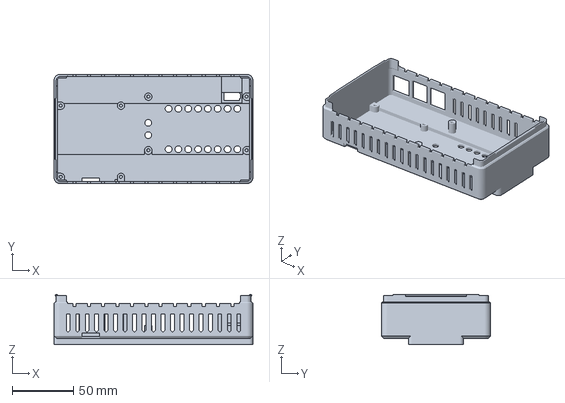
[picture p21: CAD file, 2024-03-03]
3d_printing/3d/PiPLC-CaseTop.3mf
162.0 x 89.0 x 40.8 mm

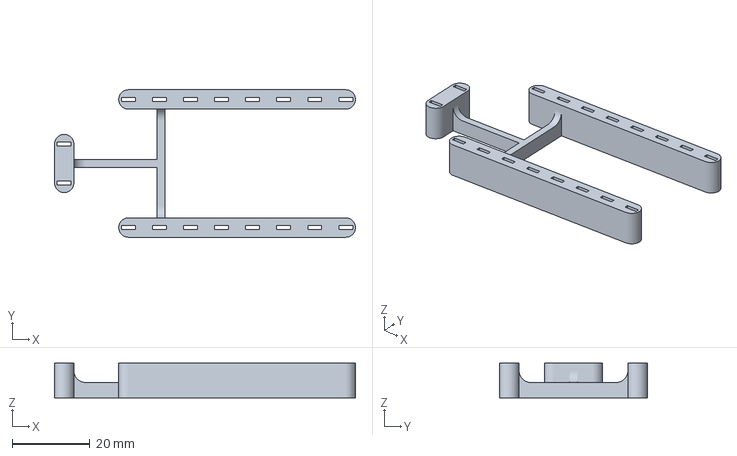
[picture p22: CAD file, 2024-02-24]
3d_printing/3d/PiPLC-HMILED_Spacer.3mf
77.5 x 38.0 x 9.00 mm

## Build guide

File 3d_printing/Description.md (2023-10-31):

# Project

# Part

For general information and building instructions about this project please see the [**Github page**](TODO link here if applicable)!

## TODO description here

> If you need one of my things printed or you want to suggest a modification on a part please drop me a message!

> If you print one of my things i would be happy about some feedback and a make!

> If you like my things please consider [**supporting me**](https://github.com/Chrismettal#donations)!

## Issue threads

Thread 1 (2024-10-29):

NCN5121 Schematic

dzungpv, 2024-10-29:
I want to ask more about NCN5121.
You design not mention in the datasheet. So in your design use are using external 3.3v to power the chip and not using any of LDO and on chip DC/DC. And the ground for the Pi and KNX the same, but the difference in the voltage.
Do you test it in real life? Because I have the same schematic but I use DC/DC converter 1 to power the chip and connected with Pi by common ground (TX, RX and GND to Pi), but sometime it cause data error.

Chrismettal, 2024-10-29:
You are correct, the NC5121 design used in PiPLC is not one of the application examples listed in the NCN5121 datasheet.

I am not using the on-board DC/DC as I already have all the voltages required present and don't need to supply any of PiPLC from the usually pretty limited KNX supplies. They are helpful when designing a device that lives parasitically only from KNX but with this design it didn't make sense to draw power from the KNX.

It would have made sense to keep the NCN5121 running from KNX power and having the Pi be isolated through a UART isolator but that's something for another version.

The design is proven and is currently running in 3 deployed systems. I did not yet see any data loss and can reliably read and write from/to the KNX with the design as implemented.

dzungpv, 2024-10-30:
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

Thank you for the information.

dzungpv, 2024-11-15:
@Chrismettal I make KNX adapter for Pi4b base on your schematics with some modified, but it not working. I tested the board with Siemens N148 and it work (I using knx stack and try to program it with ETS), so not the hardware issue.

But when I install it to the Pi4b with KNXD add-on follow your guide here [interface-ncn5120] Link down](https://github.com/Chrismettal/PiPLC?tab=readme-ov-file#wago-header--knx--ncn5121) for Home Assistance it not working: show error:

```
F00000105: [15:interface-ncn5120] Link down, terminating
```

I also try usb driver and tpuart driver still the same.

My config:

```
address: 15.15.1
client_address: 15.15.2:8
interface: nc5120
log_error_level: warning
usb_filters: single
dest_port: "99"
device: /dev/ttyAMA0
baudrate: 19200
```

Can you share your working config?

Chrismettal, 2024-11-15:
Have you followed the guide to enable NC5120 communication on the Pi?

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

You can also try installing knxd in bare linux on the pi without HASS to debug your system. Might be easier than going through the KNXd addon first.

This is my working config:

```
address: 0.0.1
client_address: 0.0.2:8
interface: ncn5120
device: /dev/ttyAMA0
log_error_level: warning
usb_filters: single
ip_address: 0.0.0.0
dest_port: "99"
custom_config: ""
```

dzungpv, 2024-11-15:
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

Yes, This is my hardware information in HA:
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

I also try UART4, the same.

dzungpv, 2024-11-17:
It working now, because tty not disable on the HA, I read this issue  and do some additional command to disable it and it work https://github.com/knxd/knxd/issues/514

Closed 2024-10-30.

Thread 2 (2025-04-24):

PCB/Schematic Questions

CameronBrooks11, 2025-04-24:
Hello,

Nice project thanks for sharing! I was looking at the KiCad files and I have a question first before I modify the board to add CAN and some other minor tweaks for my use case...and then attempt to order from JLC to make it myself.

**_pcb/_**

**PiPLC-24VDO**

It's unclear as to what the purpose of this schematic is...I can see that it has components of the relay subcircuit on the mainboard. Should it be deleted?

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

**PiPLC-Mainboard**

There are unconnected nets on the relays and a confusing connection scheme:

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

and the connection scheme is confusing to me considering they are all connected identically on the schem:

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

Chrismettal, 2025-04-24:
Good Morning,

the 24VDO subboard isn't done yet, but isn't to be deleted. It isn't required for general operation. The intention is to have this subboard be a drop-in replacement for the Relays, providing industrial 24V logic outputs instead of relay dry contacts.

And for the mainboard, as you can see the pitch of the relays and the pitch of the contacts they wire up to is different for space reasons, so the routing needs to differ to accomodate. I've aimed to fit the largest possible routing width, which meant that I had to alternate the routing directions. They *are* all connected the same though. The upper row is always connected to the right terminal of the respective output, and the lower row connects to the left terminal.
The unrouted nests are connected *inside* the relay so routing them is luckily redundant. If I did route them, I would have needed to greatly reduce routing width and wouldn't have been able to double-up on the size.

So in short, I traded higher current throughput capabilities for routing readability.

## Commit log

2023-10-31 [PCB] Start wiring GPIOs up
    [PiPLC-Base.kicad_pcb, PiPLC-Base.kicad_sch]
2023-10-31 [PCB] Start adding KNX functionality
    [PiPLC-Base.kicad_pcb, PiPLC-Base.kicad_sch]
2023-11-01 [PCB] Finish initial KNX schematic
    [PiPLC-Base.kicad_sch]
2023-11-01 [PCB] Wire up DIs
    [PiPLC-Base.kicad_sch]
2023-11-01 Add GPIO mapping table to readme
    [PiPLC-Base.kicad_sch]
2023-11-01 Add todo for better DI input protection
    [PiPLC-Base.kicad_sch]
2023-11-02 [PCB] Update DI and start designing DQ
    [PiPLC-Base.kicad_sch]
2023-11-02 Finish wiring up DQs
    [PiPLC-Base.kicad_sch]
2023-11-03 Optimize schematic a bit
    [PiPLC-Base.kicad_sch]
2023-11-03 Optimize part choice and assign most footprints
    [PiPLC-Base.kicad_sch]
2023-11-03 Assign all 3D models
    [PiPLC-Base.kicad_pcb, PiPLC-Base.kicad_sch]
2023-11-05 Add 3D files for MSTB plugs
    [PiPLC-Base.kicad_pcb]
2023-11-06 Move Pi to align outer edges of PCBs
    [PiPLC-Base.kicad_pcb]
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2023-11-06 Split some parts of Mainboard off to Frontpanel
    [PiPLC-Base.kicad_pcb, PiPLC-Base.kicad_sch, PiPLC-Frontpanel.kicad_pcb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]
2023-11-06 Throw all frontpanel pieces on the board somewhere
    [PiPLC-Frontpanel.kicad_pcb, PiPLC-Frontpanel.kicad_sch]
2023-11-06 Move stuff on both PCBs for 3D proof of concept
    [PiPLC-Base.kicad_pcb, PiPLC-Frontpanel.kicad_pcb]
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2023-11-11 Minor cleanup on main board
    [PiPLC-Base.kicad_pcb, PiPLC-Base.kicad_sch]
2023-11-11 Add decoupling / filtering to all IC's and relays
    [PiPLC-Base.kicad_pcb, PiPLC-Base.kicad_sch]
2023-11-11 [HMI] Move mechanical bits
    [PiPLC-Frontpanel.kicad_pcb]
2023-11-12 Rename both PCBs and align their connector
    [PiPLC-HMI.kicad_pcb, PiPLC-HMI.kicad_sch, PiPLC-Mainboard.kicad_pcb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]
2023-11-12 [HMI] Move LEDs up by 3mm
    [PiPLC-HMI.kicad_pcb]
2023-11-12 Add Pi riser board
    [PiPLC-Mainboard.kicad_pcb, PiPLC-PiRiser.kicad_pcb, PiPLC-PiRiser.kicad_sch]
2023-11-12 [PiRiser] Double up routing
    [PiPLC-PiRiser.kicad_pcb]
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2023-11-12 [PiRiser] Reduce bottom edge by 0.25mm
    [PiPLC-PiRiser.kicad_pcb]
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2023-11-12 [HmiRiser] Add HMI riser board
    [PiPLC-HmiRiser.kicad_pcb, PiPLC-HmiRiser.kicad_sch]
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2023-11-12 Add "5V OK" and "24V OK" LEDs to HMI
    [PiPLC-HMI.kicad_pcb, PiPLC-HMI.kicad_sch, PiPLC-Mainboard.kicad_sch]
2023-11-12 [Front] Add front panel
    [PiPLC-Frontpanel.kicad_pcb, PiPLC-Frontpanel.kicad_sch]
2023-11-13 [HMI] Add LCSC part number for 1mm pins
    [PiPLC-HMI.kicad_sch]
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2023-11-13 [Main] Double check pin header pinouts
    [PiPLC-Mainboard.kicad_pcb, PiPLC-Mainboard.kicad_sch]
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2023-11-13 [Main] Start positioning parts
    [PiPLC-Mainboard.kicad_pcb, PiPLC-Mainboard.kicad_sch]
2023-11-13 [HMI] Flip pin assignment of boardboard interface
    [PiPLC-HMI.kicad_pcb, PiPLC-HMI.kicad_sch]
2023-11-13 [Main] Route the easy stuff
    [PiPLC-Mainboard.kicad_pcb]
2023-11-16 Add termination resistor to Modbus terminal
    [PiPLC-Mainboard.kicad_pcb, PiPLC-Mainboard.kicad_sch]
2023-11-19 [Mainboard] Double check Pi header
    [PiPLC-Mainboard.kicad_sch]
2023-11-19 [Main] Continue routing mainboard
    [PiPLC-Mainboard.kicad_pcb]
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2023-11-21 Guess what, more routing
    [PiPLC-Mainboard.kicad_pcb]
2023-11-22 You guessed it, routing
    [PiPLC-Mainboard.kicad_pcb, PiPLC-Mainboard.kicad_sch]
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2023-11-25 [Main] Run DRC. Ignored items:
    - Unconnected nets of redundant relay pins
    - Clearence shows 0,199 actual on many nets for some reason
    - Some GND connections don't hit thermal spoke mins
    [PiPLC-Mainboard.kicad_pcb]
2023-11-25 [Main] Fix silkscreen
    [PiPLC-Mainboard.kicad_pcb]
2023-11-25 [Main] Beautify PCB somewhat
    [PiPLC-Mainboard.kicad_pcb]
2023-11-25 [HMI] Route and beautify
    [PiPLC-HMI.kicad_pcb]
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2023-11-25 [HMI] Add JLC board number
    [PiPLC-Frontpanel.kicad_pcb]
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2023-11-26 [Main] Fix wrong value for Modbus plug
    [PiPLC-Mainboard.kicad_pcb, PiPLC-Mainboard.kicad_sch]
2023-11-26 [PiRiser][HmiRiser] Update LCSC part numbers on PCB file
    [PiPLC-HmiRiser.kicad_pcb, PiPLC-PiRiser.kicad_pcb]
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2023-11-28 [Main] Add more clearance between relay outputs and ground plane
    [PiPLC-Mainboard.kicad_pcb, bom.csv, designators.csv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]
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2023-12-09 [Doc] Fix PWM adresses in mapping table
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2023-12-13 Fix modbus pin labeling
    [PiPLC-Mainboard.kicad_sch]
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2024-01-27 [Mainboard] Change DC-DC output voltage to 5.2 V while raising max current to 3A
    [PiPLC-Mainboard.kicad_pcb, PiPLC-Mainboard.kicad_sch]
2024-01-28 [Mainboard] Add optional 1-Wire pullup
    [PiPLC-Mainboard.kicad_pcb, PiPLC-Mainboard.kicad_sch]
2024-01-28 [Mainboard] Add net labels for Modbus A/B
    [PiPLC-Mainboard.kicad_sch]
2024-01-28 [Mainboard] Add automatic DE/NRE option for Modbus transceiver
    [PiPLC-Mainboard.kicad_pcb, PiPLC-Mainboard.kicad_sch]
2024-01-28 [Mainboard] Add fuse to 24V DI supply
    [PiPLC-Mainboard.kicad_pcb, PiPLC-Mainboard.kicad_sch]
2024-01-28 [Mainboard] Decouple 24V DI supply
    [PiPLC-Mainboard.kicad_pcb, PiPLC-Mainboard.kicad_sch]
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2024-01-28 [HMI] Fix Q LEDs inverted + add silk labels
    [PiPLC-HMI.kicad_pcb, PiPLC-HMI.kicad_sch]
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2024-01-28 [Mainboard] Add ground connector to Relay footprint for addon board
    [PiPLC-Mainboard.kicad_pcb, PiPLC-Mainboard.kicad_sch]
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2024-02-18 [Mainboard] Fix 3D model path for plugs
    [PiPLC-Mainboard.kicad_pcb]
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2024-02-24 [3D] "Finalize" case, export 3mf files and generate gcodes for PrusaXL
    [PiPLC-CaseBot.3mf, PiPLC-CaseTop.3mf, PiPLC-HMILED_Spacer.3mf]
2024-02-29 [3D] Update GCode for top file to only use a single filament
    [PiPLC-CaseTop.3mf]
2024-03-03 [3d] update case to give 1mm more insertion back
    [PiPLC-CaseBot.3mf, PiPLC-CaseTop.3mf]
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2024-05-31 PENDING VALIDATION - Update to new KiCAD version - update current limit resistors to not burn my eyes out
    [PiPLC-Mainboard.kicad_pcb, PiPLC-Mainboard.kicad_sch]

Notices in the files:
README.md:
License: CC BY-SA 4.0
